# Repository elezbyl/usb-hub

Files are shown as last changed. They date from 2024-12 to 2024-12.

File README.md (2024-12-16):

# USB HUB Board Project

<p align="right">
  
</p>

USB HUB Board project is an open source project described by following:
* USB 3.0 upstream port,
* four USB 3.0 downstream ports,
* MCU on board for management and telemetry,
* simple host-to-MCU interfaces based on USB VCP/CDC,
* two USB 3.0 HUB devices, first - unmanageable (always enabled) with MCU and second HUB connected behind, second - manageable by the MCU,
* downstream ports with power enabling/disabling,
* downstream ports with overcurrent protection,
* downstream ports with power consumption monitoring,
* main system voltages rails power consumption monitoring.

USB HUB Board high level diagram is available here:
[High Level](arch/high_level.md)

Repository contains multiple components like ARCH, HW, FW, SW and DOCs.

To prepare the repository:
```
git clone --recurse-submodules https://github.com/elezbyl/usb-hub.git
```
# ARCH
More details can be found [here](arch/README.md)

# HW
More details can be found [here](hw/README.md)

# FW
More details can be found [here](fw/README.md)

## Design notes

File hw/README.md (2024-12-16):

# USB HUB Project Hardware
USB HUB hardware project for USB HUB device.

## EDA
Project is prepared with KiCAD

### Version
Version: 8.0.5, release build

Libraries:
* wxWidgets 3.2.5
* FreeType 2.13.2
* HarfBuzz 9.0.0
* FontConfig 2.14.2
* libcurl/8.8.0-DEV Schannel zlib/1.3.1

Build Info:
* Date: Sep 7 2024 02:39:48
* wxWidgets: 3.2.5 (wchar_t,wx containers)
* Boost: 1.85.0
* OCC: 7.8.1
* Curl: 8.8.0-DEV
* ngspice: 42
* Compiler: Visual C++ 1939 without C++ ABI

## Components

* Main USB HUB: TUSB8041
    * package: VQFN-64
    * [details](https://www.ti.com/lit/ds/symlink/tusb8041.pdf)
* Additional USB HUB: TUSB8020B
    * package: HTQFP-48
    * [details](https://www.ti.com/lit/gpn/TUSB8020B)
* Microcontroller: STM32G441RBTx
    * package: LQFP-64
    * [details](https://www.st.com/en/microcontrollers-microprocessors/stm32g441kb.html)
* 3.3V VR: LDO 1117-3.3 (3.3V/1A) LDO
    * package: SOT-223
    * [details](https://www.st.com/resource/en/datasheet/ld1117.pdf)
* 1.1V VR: DC/DC Buck: TPS54531
    * package: 
    * [details](https://www.ti.com/lit/ds/slvsbi5/slvsbi5.pdf)
* Current-Sense Amplifier: INA180
    * package: SOT-23(5)
    * [details](https://www.ti.com/lit/ds/symlink/ina180.pdf)
* Current-limited power switch: TPS2561
    * package: VSON-10
    * [details](https://www.ti.com/lit/ds/symlink/tps2561.pdf)
* EEPROM: AT24C04
    * package: SOIC-8
    * [details](https://ww1.microchip.com/downloads/en/DeviceDoc/doc0180.pdf)
* Resistors: SMT, 0402 and 0603
* Current measure resistors: SMT, 0.5%, 1206
* Capacitors: SMT, 0603 and 0805
* Headers: 2.54mm
* USB connectors:
    * upstream: THT, USB 3.0 B
    * downstream: THT, USB 3.0 A
* External DC connector: 5.5/2.1mm barrel power jack
* LEDs: SMT
* Push-buttons: SMT

## Additional documents

USB HUB:
* [User guide: TUSB8041RGC REVD Evaluation Module User's Guide](https://www.ti.com/lit/pdf/sllu198)
* [Design guide: 2-Port USB 3.0 Hub (TIDA-00287)](https://www.ti.com/lit/pdf/tidu428)
* [Application note: High-Speed Layout Guidelines for Signal Conditioners and USB Hubs](https://www.ti.com/lit/pdf/slla414)
* [Selection and Specification of Crystals for Texas Instruments USB 2.0 Devices](https://www.ti.com/lit/an/slla122/slla122.pdf)

MCU:
* [AN2867: Application note: Guidelines for oscillator design on STM8AF/AL/S and STM32 MCUs/MPUs](https://www.st.com/resource/en/application_note/an2867-guidelines-for-oscillator-design-on-stm8afals-and-stm32-mcusmpus-stmicroelectronics.pdf)
* [STM32 MCU Series HSE MHz Crystal Selection Tool](https://ecsxtal.com/stm32-mcu-series-hse-mhz-crystal-selection-tool/)
* [AN1709: Application note: EMC design guide for STM8, STM32 and legacy MCUs](https://www.st.com/resource/en/application_note/an1709-emc-design-guide-for-stm8-stm32-and-legacy-mcus-stmicroelectronics.pdf)
* [AN2606: STM32 microcontroller system memory boot mode](https://www.st.com/resource/en/application_note/an2606-stm32-microcontroller-system-memory-boot-mode-stmicroelectronics.pdf)
* [AN5093: Getting started with STM32G4 Series hardware development boards](https://www.st.com/resource/en/application_note/an5093-getting-started-with-stm32g4-series--hardware-development-boards-stmicroelectronics.pdf)
* [AN4879: Introduction to USB hardware and PCB guidelines using STM32 MCUs](https://www.st.com/resource/en/application_note/an4879-introduction-to-usb-hardware-and-pcb-guidelines-using-stm32-mcus-stmicroelectronics.pdf)
* [Wiki: Basics of power supply design for STM32 MCU](https://wiki.st.com/stm32mcu/wiki/Basics_of_power_supply_design_for_MCU)
* [Wiki: Introduction to USB with STM32](https://wiki.st.com/stm32mcu/wiki/Introduction_to_USB_with_STM32)
* [Training: STM32G4 System Power](https://www.st.com/resource/en/product_training/STM32G4-System-Power_control_PWR.pdf)

## Current consumption
Power architecture details can be found [here](../arch/power.md). It shows power rails derivation and power rails topology.

Below is the list of all system power rails with details about how they are derived.

* 1.1V SYS:
    * 1.1V power rails used to supply the USB HUB ICs,
    * derived from 5.0V SYS,
* 3.3V SYS:
    * 3.3V power rails used to supply all the ICs on the board (MCU, USB HUB, EEPROM, current sense IC)
    * derived from 5.0V SYS,
* 5.0V DNx:
    * 5.0V power rails used to supply USB downstream ports
    * derived from 5.0V SYS,
* 5.0V SYS:
    * 5.0V power rail, the main one,
    * derived from 5.0V EXT (external +5.0V DC power supply) or host USB 3.0 upstream (up to 900mA\4.5W),

In the table below there is list of board's components along with their theoretical maximal power consumption.

USB HUB ICs are not included. See next paragraph for USB HUB ICs.

| Component | 3.3V SYS |
| --- | --- |
| MCU | 50mA |
| EEPROM | 5mA (x2) |
| Current Sense Amp | 8mA (x7) |
| LED | 5mA (x8) |
| AND gate | 1mA (x4) |
| Power Switch | 1mA (x2) |
| | |
| Total | 162mA |

It gives 162mA @ 3.3V SYS. 3.3V SYS is derived from 5.0 SYS using LDO so related power consumption @ 5.0V SYS is 162mA * 5.0V = **810mW**

USB HUB ICs power consumption depend on USB topology (number and type of USB device connected to the board). In the table below there is list of a few configurations along with theoretical maximal power consumption.

In the table below there is a power consumption done by USB HUB ICs at 1.1V SYS power rail.

| Configuration | 1.1V SYS | Power @ 1.1V SYS  |
| --- | --- | --- |
| 4 SS | 778mA (TUSB8041) <br> 364mA (TUSB8020B) | 1256mW |
| 3 SS | 661mA (TUSB8041) <br> 364mA (TUSB8020B) | 1128mW |
| 2 SS | 508mA (TUSB8041) <br> 364mA (TUSB8020B) | 959mW |
| 1 SS | 366mA (TUSB8041) <br> 364mA (TUSB8020B) | 803mW |
| 4 HS | 86mA (TUSB8041) <br> 364mA (TUSB8020B)  | 495mW |
| 1 SS | 63mA (TUSB8041) <br> 364mA (TUSB8020B)  | 479mW |
| 2 SS + 2 HS | 554mA (TUSB8041) <br> 364mA (TUSB8020B) | 1010mW |
| 1 SS + 1 HS | 395mA (TUSB8041) <br> 364mA (TUSB8020B) | 835mW |

In the table below there is a power consumption done by USB HUB ICs at 3.3V SYS power rail.

| Configuration | 3.3V SYS | Power @ 3.3V SYS  |
| --- | --- | --- |
| 4 SS | 49mA (TUSB8041) <br> 93mA (TUSB8020B) | 469mW |
| 3 SS | 49mA (TUSB8041) <br> 93mA (TUSB8020B) | 469mW |
| 2 SS | 49mA (TUSB8041) <br> 93mA (TUSB8020B) | 469mW |
| 1 SS | 49mA (TUSB8041) <br> 93mA (TUSB8020B) | 469mW |
| 4 HS | 76mA (TUSB8041) <br> 93mA (TUSB8020B) | 558mW |
| 1 SS | 45mA (TUSB8041) <br> 93mA (TUSB8020B) | 455mW |
| 2 SS + 2 HS | 99mA (TUSB8041) <br> 93mA (TUSB8020B) | 634mW |
| 1 SS + 1 HS | 85mA (TUSB8041) <br> 93mA (TUSB8020B) | 588mW |

In the table below there is a power consumption done by USB downstream devices at 5.0V SYS power rail.

| Configuration | 5.0V DNx | Power @ 5V SYS DN |
| --- | --- | --- |
| 4 SS | 4 x 900mA | 18W |
| 3 SS | 3 x 900mA | 13.5W |
| 2 SS | 2 x 900mA | 9W |
| 1 SS | 1 x 900mA | 4.5W |
| 4 HS | 4 x 500mA | 10W |
| 1 SS | 1 x 500mA | 2.5W |
| 2 SS + 2 HS | 2 x 900mA + 2 x 500mA | 14W |
| 1 SS + 1 HS | 1 x 900mA + 1 x 500mA | 7W |

In the table below there is a total power consumption done by USB HUB ICs and USB downstream devices.
Values below includes power loss during DC/DC conversion. Following rules used:

* 5.0V SYS -> 1.1V SYS conversion efficiency: 90% (step-down converter used, taken from TPS54531 specification)
* 5.0V SYS -> 3.3V SYS conversion efficiency: 66% (LDO used, =3.3/5.0)
* 5.0V SYS -> 5.0V DNx conversion efficiency: 100% (no DC/DC conversion)

| Configuration | 1.1V SYS -> 5.0V SYS | 3.3V SYS -> 5.0V SYS | 5.0V SYS DN -> 5.0V SYS | Total at 5.0V SYS |
| --- | --- | --- | --- | --- |
| 4 SS | 1256 / 0.9 = 1396mW | 469 / 0.66 = 711mW | 18W | 20.107W |
| 3 SS | 1128 / 0.9 = 1253mW | 469 / 0.66 = 711mW | 13.5W | 15.339W |
| 2 SS | 959  / 0.9 = 1066mW | 469 / 0.66 = 711mW | 9W | 10.777W |
| 1 SS | 803  / 0.9 = 892mW | 469 / 0.66 = 711mW | 4.5W | 6.103W |
| 4 HS | 495  / 0.9 = 550mW | 558 / 0.66 = 845mW | 10W | 11.345W |
| 1 HS | 479  / 0.9 = 532mW | 455 / 0.66 = 689mW | 2.5W | 3.721W |
| 2 SS + 2 HS | 1010 / 0.9 = 1122mW | 634 / 0.66 = 961mW | 14W | 16.083W |
| 1 SS + 1 HS | 835  / 0.9 = 928mW | 588 / 0.66 = 891mW | 7W | 8.819W |

Conclusions:

* Total theoretical maximal power consumption (@ 5.0V SYS) is: 0.81 + 20.107 = **20.817W**
* Supplying from USB 3.0 upstream port would be enough to satisfy USB configuration with single USB HS device available only
* When more than one USB downstream ports are populated or having at least one USB SS device available - external power supply is required (minimum 5V/20W)

## PCB

### Vendor
[JLCPCB](https://jlcpcb.com)

### Details
* Material: FR4-TG155, JLC06161H-3313: [details](https://jlcpcb.com/help/article/User-Guide-to-the-JLCPCB-Impedance-Calculator)
* Layers count: 6 (L1.Signal, L2.GND, L3.Signal, L4.VCC, L5.GND, L6.Signal)
* PCB Thickness: 1.54mm (-/+ 10%)
* Prepreg: 3313 RC57%
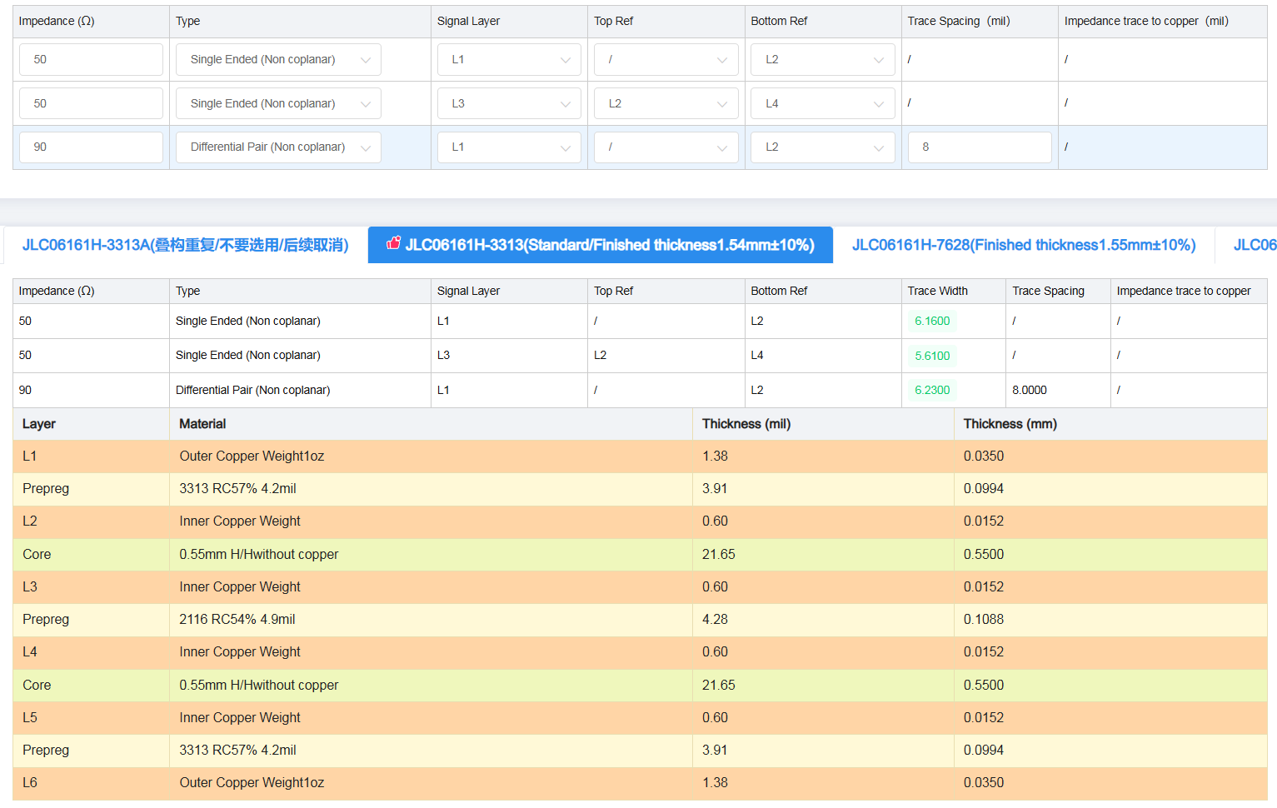
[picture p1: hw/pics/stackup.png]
* PCB stackup: 
    * [source](https://jlcpcb.com/pcb-impedance-calculator)
* Via hole:
  * 12mils (0.3mm) for signals
  * 15mils (0.38mm) for power 1
  * 20mils (0.5mm) for power 2
* Via diameter:
  * 30mils (0.64mm) for signals
  * 35mils (0.89mm) for power 1
  * 45mils (1.00mm) for power 2
* Via annular ring:
  * 9mils (0.23mm) for signal
  * 10mils (0.25mm) for power 1
  * 15mils (0.38mm) for power 2
* Silkscreen: 30mils x 30mils x 6mils

More details about JLCPCB capabilities can be found [here](https://jlcpcb.com/capabilities/pcb-capabilities)

## Design
### Version 1.00
[SCH](doc/usb-hub_sch_v1p00.pdf)

[PCB](doc/usb-hub_pcb_v1p00.pdf)

[GERBERS](gerbers/gerbers_v1p00.zip)

[BOM](bom.csv)

BOARD:
Board

Board Populated

## Tests
TBD

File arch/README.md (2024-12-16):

# USB HUB Board architecture for both HW and FW

# HW
## High Level
[High Level architecture](high_level.md)

## Power
[Power architecture](power.md)

## Power sensing
[Power Sensing architecture](power_sensing.md)

# FW
TBD

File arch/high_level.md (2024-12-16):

```mermaid
flowchart LR
    subgraph BOARD
        subgraph Power
            BARREL_JACK[Barrel Jack]
            5V_EXT[5.0V external]
            5V_USB_UP[5.0V USB]
            5V_SYS[5.0V SYS]
            3V3_SYS[3.3V SYS]
            1V1_SYS[1.1V SYS]

            BARREL_JACK --> 5V_EXT
            5V_USB_UP --> 5V_SYS
            5V_EXT --> 5V_SYS
            5V_SYS --> 3V3_SYS
            5V_SYS --> 1V1_SYS
        end
        subgraph MCU
            STM32
            JTAG
            UART

            STM32 <--> JTAG
            STM32 <--> UART

        end
        subgraph USB_UP
            HUB_2DN[USB HUB]
            EEPROM_UP[EEPROM]
            STRAPS_UP[STRAPs]
            USB3B_CONN[USB3 B connector]

            USB3B_CONN -- "USB3" --> HUB_2DN
            STRAPS_UP --> HUB_2DN
            HUB_2DN <-- "I2C" --> EEPROM_UP
        end
        subgraph USB_DOWN
            HUB_4DN[USB HUB]
            EEPROM_DOWN[EEPROM]
            STRAPS_DOWN[STRAPs]
            POWER_CTRL[Power Control]
            USB3A_CONN_DNx[USB3 A connector for DNx]
            I2C

            POWER_CTRL -- "+5.0V" --> USB3A_CONN_DNx
            HUB_4DN -- "+5.0V disable" --> POWER_CTRL
            HUB_4DN -- "USB3" --> USB3A_CONN_DNx
            STRAPS_DOWN --> HUB_4DN
            HUB_4DN <--> I2C
            EEPROM_DOWN <--> I2C
        end

        %% Power
        5V_SYS -- "+5.0V" --> POWER_CTRL
        STM32 -- "+5.0V disable" --> POWER_CTRL

        %% USB signals
        HUB_2DN -- "USB2" --> STM32
        HUB_2DN -- "USB3" --> HUB_4DN

        %% USB HUB downstream management
        STM32 <-- "IO" --> STRAPS_DOWN
        STM32 <--> I2C

    end
```

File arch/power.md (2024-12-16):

```mermaid
flowchart LR
    subgraph HUB
        subgraph Power
            BARREL_JACK[Barrel Jack]
            5V_EXT[5.0V external]
            5V_USB_UP[5.0V USB]
            5V_SYS[5.0V SYS]
            3V3_SYS[3.3V SYS]
            1V1_SYS[1.1V SYS]

            BARREL_JACK --> 5V_EXT
            5V_USB_UP --> 5V_SYS
            5V_EXT --> 5V_SYS
            5V_SYS --> 3V3_SYS
            5V_SYS --> 1V1_SYS
        end
        subgraph MCU
            STM32
            JTAG
            UART
            LED

        end
        subgraph USB_UP
            HUB_2DN[USB HUB]
            EEPROM_UP[EEPROM]
            STRAPS_UP[STRAPs]
            USB3B_CONN[USB3 B connector]
        end
        subgraph USB_DOWN
            HUB_4DN[USB HUB]
            EEPROM_DOWN[EEPROM]
            STRAPS_DOWN[STRAPs]
            POWER_CTRL[Power Control]
            USB3A_CONN_DNx[USB3 A connector for DNx]
            AND_GATE[AND gate]

            HUB_4DN -- "+5.0V disable" --> AND_GATE
            AND_GATE -- "+5.0V enable" --> POWER_CTRL
            POWER_CTRL -- "+5.0V failure" --> HUB_4DN
            POWER_CTRL -- "+5.0V" --> USB3A_CONN_DNx
        end

        %% Power
        USB3B_CONN -- "+5.0V USB" --> 5V_USB_UP
        5V_SYS -- "+5.0V" --> POWER_CTRL
        STM32 -- "+5.0V disable" --> AND_GATE
        3V3_SYS -- "+3.3V" --> STM32
        3V3_SYS -- "+3.3V" --> JTAG
        3V3_SYS -- "+3.3V" --> LED
        3V3_SYS -- "+3.3V" --> HUB_2DN
        3V3_SYS -- "+3.3V" --> EEPROM_UP
        3V3_SYS -- "+3.3V" --> STRAPS_UP
        3V3_SYS -- "+3.3V" --> HUB_4DN
        3V3_SYS -- "+3.3V" --> EEPROM_DOWN
        3V3_SYS -- "+3.3V" --> STRAPS_DOWN
        3V3_SYS -- "+3.3V" --> AND_GATE
        1V1_SYS -- "+1.1V" --> HUB_2DN
        1V1_SYS -- "+1.1V" --> HUB_4DN

    end
```

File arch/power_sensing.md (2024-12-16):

```mermaid
flowchart LR
    subgraph HUB
        subgraph Power
            BARREL_JACK[Barrel Jack]
            5V_EXT[5.0V external]
            5V_USB_UP[5.0V USB]
            5V_SYS[5.0V SYS]
            3V3_SYS[3.3V SYS]
            1V1_SYS[1.1V SYS]
            5V[5.0V]
            3V3[3.3V]
            1V1[1.1V]
            RSENSE_5V[R-sense]
            RSENSE_3V3[R-sense]
            RSENSE_1V1[R-sense]

            BARREL_JACK --> 5V_EXT
            5V_USB_UP --> 5V
            5V_EXT --> 5V
            5V --> RSENSE_5V
            RSENSE_5V --> 5V_SYS

            5V_SYS --> 3V3
            3V3 --> RSENSE_3V3
            RSENSE_3V3 --> 3V3_SYS

            5V_SYS --> 1V1
            1V1 --> RSENSE_1V1
            RSENSE_1V1 --> 1V1_SYS
        end
        subgraph MCU
            subgraph STM32
                ADC
            end
        end
        subgraph USB_UP
            USB3B_CONN[USB3 B connector]
        end
        subgraph USB_DOWN
            HUB_4DN[USB HUB]
            POWER_CTRL[Power Control]
            USB3A_CONN_DNx[USB3 A connector]
            AND_GATE[AND gate]
            RSENSE_5V_DNx[R-sense]

            HUB_4DN -- "+5.0V disable" --> AND_GATE
            AND_GATE -- "+5.0V enable" --> POWER_CTRL
            POWER_CTRL -- "+5.0V failure" --> HUB_4DN
            USB3A_CONN_DNx[USB3 A connector for DNx]

            POWER_CTRL -- "+5.0V" --> RSENSE_5V_DNx
            RSENSE_5V_DNx -- "+5.0V" --> USB3A_CONN_DNx
        end

        %% Power
        USB3B_CONN -- "+5.0V USB" --> 5V_USB_UP
        5V_SYS -- "+5.0V" --> POWER_CTRL
        STM32 -- "+5.0V disable" --> AND_GATE

        %% Power sensing
        RSENSE_5V -- "+5.0V sensing" --> ADC
        RSENSE_3V3 -- "+3.3V sensing" --> ADC
        RSENSE_1V1 -- "+1.1V sensing" --> ADC
        RSENSE_5V_DNx -- "DNx +5V sensing" --> ADC

    end
```

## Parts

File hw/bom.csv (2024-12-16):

Reference | Value | Footprint | DNP | Qty | Farnell | Mouser
C201,C506,C512,C518,C524 | 150u | Capacitor_SMD:CP_Elec_6.3x7.7 |  | 5 | 2466196 | 710-865060345006
C202,C203,C204,C205,C312,C408,C417,C540,C545 | 10u | Capacitor_SMD:C_0805_2012Metric_Pad1.18x1.45mm_HandSolder |  | 9 | ~ | ~
C206,C306,C307,C405,C406,C554,C555 | 10p | Capacitor_SMD:C_0603_1608Metric_Pad1.08x0.95mm_HandSolder |  | 7 | ~ | ~
C207,C210,C211,C212,C525,C526,C527,C528 | 1n | Capacitor_SMD:C_0603_1608Metric_Pad1.08x0.95mm_HandSolder |  | 8 | ~ | ~
C208 | 8.2n | Capacitor_SMD:C_0603_1608Metric_Pad1.08x0.95mm_HandSolder |  | 1 | ~ | ~
C209,C213,C214,C215,C301,C302,C303,C304,C305,C310,C311,C313,C314,C315,C316,C404,C407,C409,C410,C411,C412,C413,C414,C415,C416,C418,C419,C420,C421,C422,C423,C501,C504,C505,C507,C510,C511,C513,C516,C517,C519,C522,C523,C529,C530,C531,C532,C533,C534,C535,C536,C537,C538,C539,C541,C542,C543,C544,C546,C547,C548,C549,C550,C551,C552,C553 | 100n | Capacitor_SMD:C_0603_1608Metric_Pad1.08x0.95mm_HandSolder |  | 66 | ~ | ~
C308,C309 | 1u | Capacitor_SMD:C_0603_1608Metric_Pad1.08x0.95mm_HandSolder |  | 2 | ~ | ~
C401 | 10u | Capacitor_SMD:C_0603_1608Metric_Pad1.08x0.95mm_HandSolder |  | 1 | ~ | ~
C402,C403,C502,C503,C508,C509,C514,C515,C520,C521 | 100n | Capacitor_SMD:C_0402_1005Metric_Pad0.74x0.62mm_HandSolder |  | 10 | ~ | ~
D201 | B540C | Diode_SMD:D_SMC_Handsoldering |  | 1 | 2306123 | 621-B540C-F
D301,D302,D303,D304 | LED RG | LED_SMD_:LED_Wurth_155124RV73200 |  | 4 | 2764997 | 710-155124RV73200
FB201,FB202,FB203,FB301,FB401,FB402,FB501,FB502,FB503,FB504,FB505,FB506 | 220R@100MHz, 2A | Inductor_SMD:L_0805_2012Metric_Pad1.05x1.20mm_HandSolder |  | 12 | 1515661 | 81-BLM21P221SG
J201 | Barrel_Jack_Switch | Connector_BarrelJack:BarrelJack_Wuerth_6941xx301002 |  | 1 | 2472149 | 710-694106301002
J301,J402,J505 | Conn_01x03 | Connector_PinHeader_2.54mm:PinHeader_1x03_P2.54mm_Vertical |  | 3 | ~ | ~
J302 | JTAG 20pin | Connector_PinHeader_2.54mm:PinHeader_2x10_P2.54mm_Vertical |  | 1 | ~ | ~
J401 | USB3_B | Connector_USB_:USB_B_Amphenol_GSB3211xxxWEU |  | 1 | 3367999 | 523-GSB3211311WEU
J501,J502,J503,J504 | USB3_A | Connector_USB_:USB_A_Amphenol_GSB3111xxxHR |  | 4 | 3882406 | 523-GSB3111311HR
JP301 | BOOTLOADER | Connector_PinHeader_2.54mm:PinHeader_1x02_P2.54mm_Vertical |  | 1 | ~ | ~
L201 | 5.6u | Inductor_SMD_:L_Bourns_SRP6540_7.2x6.5mm_HandSolder |  | 1 | 2309901 | 652-SRP6540-5R6M
R201 | 36.5k | Resistor_SMD:R_0603_1608Metric_Pad0.98x0.95mm_HandSolder |  | 1 | ~ | ~
R202,R203,R310,R311,R312,R313,R314,R315,R316,R317,R404,R520 | 1k | Resistor_SMD:R_0603_1608Metric_Pad0.98x0.95mm_HandSolder |  | 12 | ~ | ~
R204 | 0.024R | Resistor_SMD:R_1206_3216Metric_Pad1.30x1.75mm_HandSolder |  | 1 | ~ | L4CL1206LR024DNR
R205,R206,R208,R209,R211,R212,R506,R507,R509,R510,R512,R513,R515,R516 | 5.1R | Resistor_SMD:R_0603_1608Metric_Pad0.98x0.95mm_HandSolder |  | 14 | ~ | ~
R207 | 0.3R | Resistor_SMD:R_1206_3216Metric_Pad1.30x1.75mm_HandSolder |  | 1 | 4015842 | 588-KDV12DR300ET
R210 | 0.04R | Resistor_SMD:R_1206_3216Metric_Pad1.30x1.75mm_HandSolder |  | 1 | ~ | 71-WSLP1206R0400DEA
R301,R302,R303,R304,R305,R306,R307,R308,R309,R401,R405,R406,R415,R416,R517,R521,R522,R533,R534,R535,R536,R537,R538 | 10k | Resistor_SMD:R_0603_1608Metric_Pad0.98x0.95mm_HandSolder |  | 23 | ~ | ~
R402,R518 | 90.9k | Resistor_SMD:R_0603_1608Metric_Pad0.98x0.95mm_HandSolder |  | 2 | ~ | ~
R403,R519 | 9.53k | Resistor_SMD:R_0603_1608Metric_Pad0.98x0.95mm_HandSolder |  | 2 | ~ | ~
R407,R408,R409,R410,R411,R412,R413,R414,R417,R418,R419,R420,R421,R422,R423,R424,R523,R524,R525,R526,R527,R528,R529,R530,R531,R532,R539,R540,R541,R542,R543,R544,R545,R546 | 4.7k | Resistor_SMD:R_0603_1608Metric_Pad0.98x0.95mm_HandSolder |  | 34 | ~ | ~
R425,R549 | 1M | Resistor_SMD:R_0603_1608Metric_Pad0.98x0.95mm_HandSolder | DNP | 2 | ~ | ~
R501,R502,R503,R504 | 1M | Resistor_SMD:R_0603_1608Metric_Pad0.98x0.95mm_HandSolder |  | 4 | ~ | ~
R505,R508,R511,R514 | 0.12R | Resistor_SMD:R_1206_3216Metric_Pad1.30x1.75mm_HandSolder |  | 4 | 4045438 | 588-KDV12DR120ET
R547,R548 | 46.4k | Resistor_SMD:R_0603_1608Metric_Pad0.98x0.95mm_HandSolder |  | 2 | ~ | ~
SW201 | SW_SPDT | Connector_PinHeader_2.54mm:PinHeader_1x03_P2.54mm_Vertical |  | 1 | ~ | ~
SW301,SW302,SW303,SW304,SW305,SW401 | SW_Push | Button_Switch_SMD:SW_Tactile_SPST_NO_Straight_CK_PTS636Sx25SMTRLFS |  | 6 | 3780601 | 611-PTS636SK25SMTRLF
TP201 | +1.1_SYS_EN | TestPoint:TestPoint_Pad_D2.5mm |  | 1 | ~ | ~
U201 | TLV1117-33 | Package_TO_SOT_SMD:SOT-223-3_TabPin2 |  | 1 | 3122356 | 595-TLV1117LV33DCYR
U202 | TPS54531 | Package_SO:Texas_R-PDSO-G8_EP2.95x4.9mm_Mask2.4x3.1mm_ThermalVias |  | 1 | 3007357 | 595-TPS54531DDAR
U203 | INA180A3 | Package_TO_SOT_SMD:SOT-23-5 |  | 1 | 3005321 | 595-INA180A3IDBVR
U204,U205,U509,U510,U511,U512 | INA180A1 | Package_TO_SOT_SMD:SOT-23-5 |  | 6 | 3118130 | 595-INA180A1IDBVR
U301 | STM32G441RBTx | Package_QFP:LQFP-64_10x10mm_P0.5mm |  | 1 | 3132415 | 511-STM32G441RBT6
U401 | TUSB8020B | Package_QFP_:HTQFP-48-7x7mm-P0.5mm-EP7x7mm |  | 1 | ~ | 595-TUSB8020BPHPR
U402,U502 | AT24C04-SSHM | Package_SO:SOIC-8_3.9x4.9mm_P1.27mm |  | 2 | 2345581 | 556-AT24C04C-SSHM-T
U501 | TUSB8041 | Package_DFN_QFN:QFN-64-1EP_9x9mm_P0.5mm_EP6x6mm_ThermalVias |  | 1 | ~ | 595-TUSB8041RGCR
U503,U504 | TPS2560 | Package_SON:VSON-10-1EP_3x3mm_P0.5mm_EP1.65x2.4mm_ThermalVias |  | 2 | ~ | 595-TPS2560DRCR
U505,U506,U507,U508 | 74LVC1G38 | Package_TO_SOT_SMD:SOT-353_SC-70-5_Handsoldering |  | 4 | 3442031 | 771-LVC1G38GW125
Y301,Y401,Y501 | ECS-240-10-36B2-CTN | Oscillator_:Oscillator_SMD_ECS-xxx-x-36B2-xxx-4Pin_2.5x2.0mm |  | 3 | 4059099 | 520-240-10-36B2CTNTR

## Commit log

2024-12-16 README update
    Modified main README.
    Added README for FW - dummy for now
    Added README for HW - with some details already:
    * description
    * components list
    * documentation
    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
2024-12-16 USB HUB board architecture
    1. Added subdirectory for arch stuff
    2. Added high level arch diagram
    3. Added power arch diagram
    4. Added power sensing arch diagram
    5. Some minor changes in other README files.
2024-12-16 SCH v1.00
    1. All the parts of the schematics v1.00 done.
    2. BOM generated.
    3. ERC report generated: 41 issues about nets duplication ("Both AAA and BBB are attached to the same items; AAA will be used in the netlist"). All issues are ok
    4. No issues during netlist import to the PCB editor.
    5. READMEs updates
    [bom.csv, hubs.kicad_sch, mcu.kicad_sch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]
